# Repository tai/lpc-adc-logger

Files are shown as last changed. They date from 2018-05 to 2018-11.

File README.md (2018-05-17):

# 4-ch ADC Data Logger with LPC1114

This is a simple ADC data logger based on LPC1114FN28 microcontroller.
Primary motivation is to test and record battery runtime independently, without using large/external facility like a PC.

# Major Features
- Can measure voltage of 4 channels every minutes at 10-bit resolution
- Can stream data to serial port
- Can log data to FAT-formatted SD card (saves after every 60 samples)
- Can flush data to SD card with a button press
- Can erase data on SD card with a button press
- Can show activity/response to LEDs
- Supports battery-based, low power operation

# How to Build
```
$ git clone lpc-adc-logger
$ cd lpc-adc-logger
$ make
```

# How to Use
- Insert a SD card with a file LOG-00.TXT on its root folder.
- LOG-00.TXT must be prepared as a zero-filled file large enough to hold all log data.
-- Command `dd if=/dev/zero of=LOG-00.TXT bs=1024 count=1024` would do
- Pressing "Erase/Flush" button during powerup erases data in datafile.
- Pressing "Erase/Flush" button during operation flushes data to datafile.
- Connect UART to see a stream of currently sampled data.
- You can power off anytime - however, most recent page (256B) amount of data will be lost unless flushed by a button press.

# LED pattern meanings
- Fast blink - processing button press
- Slow blink - in operation

# Pinouts
- dp1  - SD card (MISO)
- dp2  - SD card (MOSI)
- dp3  - SWD (SWDCLK)
- dp4  - ADC ch#0
- dp5  - NC (reserved for I2C-SDA)
- dp6  - SD card (SCLK)
- dp7  - Analog VCC
- dp8  - Analog GND
- dp9  - ADC ch#1
- dp10 - ADC ch#2
- dp11 - ADC ch#3
- dp12 - SWD (SWDIO)
- dp13 - NC (reserved for PWM/WAKEUP)
- dp14 - Button #1 (Flush/Erase Button)
- dp15 - Serial RX
- dp16 - Serial TX
- dp17 - NC (reserved for button)
- dp18 - NC (reserved for PWM)
- dp19 - NC (XTALOUT)
- dp20 - NC (XTALIN)
- dp21 - VCC
- dp22 - GND
- dp23 - RESET
- dp24 - NC (reserved for CLKOUT)
- dp25 - SD card (SSEL)
- dp26 - LED #1
- dp27 - NC (reserved for I2C-SCL)
- dp28 - NC (reserved for LED #2)

# Schematic

# Notes
- Already functional, but currently under development. 
- Sampling rate is currently 1 sample/s, will make it 1 sample/min in final version.

# See Also
- PlatformIO
- BlackMagic
- mBed
- PFF

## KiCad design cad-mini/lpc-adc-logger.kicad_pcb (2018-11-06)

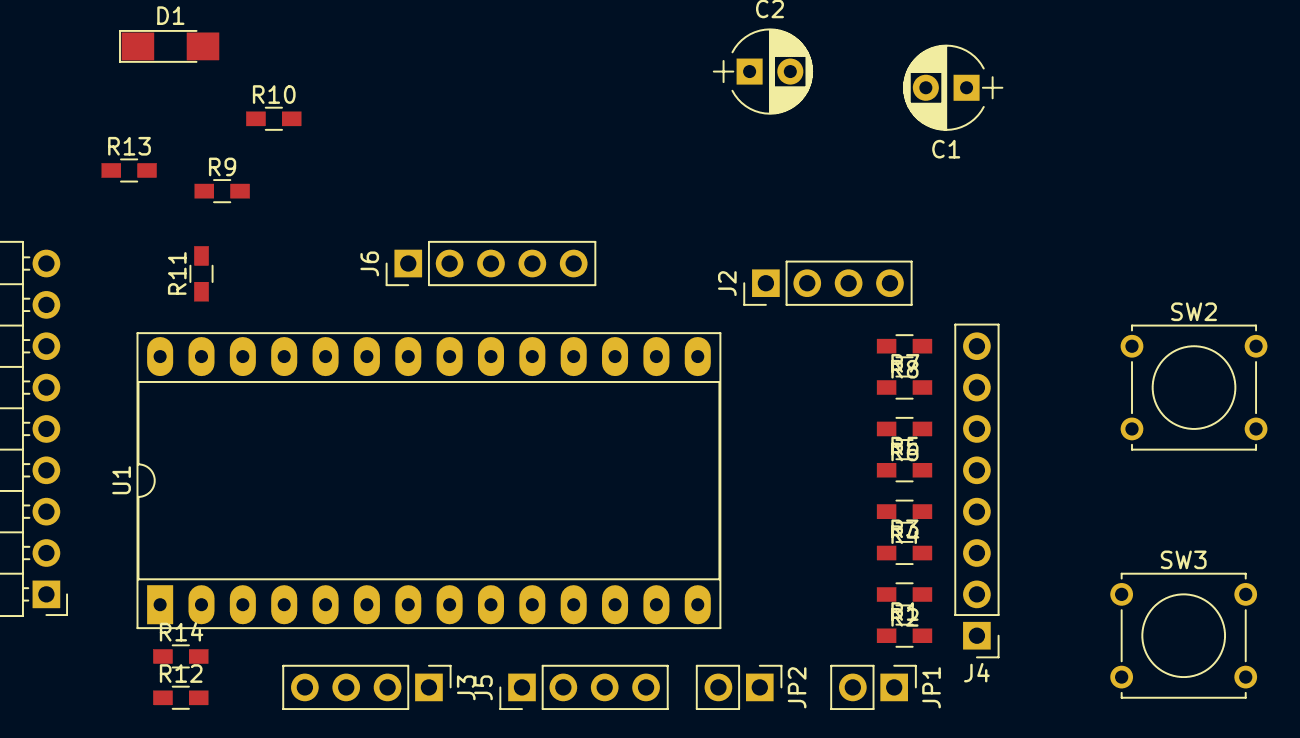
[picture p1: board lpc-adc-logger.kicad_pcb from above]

Board: 2 copper layers, 28 parts (0 on the bottom side), 29 nets, no tracks yet.

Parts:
C1, C2: 10uF; CP_Radial_D5.0mm_P2.50mm
D1: LED; LED_1206_HandSoldering
J1: SD/SPI; Pin_Header_Angled_1x09_Pitch2.54mm
J2: UART; Pin_Header_Straight_1x04_Pitch2.54mm
J3: I2C; Pin_Header_Straight_1x04_Pitch2.54mm
J4: ANALOG IN; Pin_Header_Straight_1x08_Pitch2.54mm
J5: SWD; Pin_Header_Straight_1x04_Pitch2.54mm
J6: GPIO; Pin_Header_Straight_1x05_Pitch2.54mm
JP1: RATE; Pin_Header_Straight_1x02_Pitch2.54mm
JP2: CARD; Pin_Header_Straight_1x02_Pitch2.54mm
R1, R2, R3, R4, R5, R6, R7, R8, R11, R12: 4.7K; R_0603_HandSoldering
R9: 330; R_0603_HandSoldering
R10: 10K; R_0603_HandSoldering
R13, R14: 47K; R_0603_HandSoldering
SW2: RESET; SW_Tactile_Straight_KSA0Axx1LFTR
SW3: FLUSH; SW_Tactile_Straight_KSA0Axx1LFTR
U1: LPC1114FN28; DIP-28_W15.24mm_Socket_LongPads

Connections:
/CLK: J1.6, U1.6
/CMD/MOSI: J1.3, R14.1, U1.2
/DAT0/MISO: J1.8, R13.1, U1.1
/DAT3/CS: J1.2, U1.25
GND: C1.2, C2.2, J1.4, J1.7, J2.1, J3.1, J4.2, J4.4, J4.6, J4.8, J5.1, J6.1, JP1.1, JP2.1, R2.1, R4.1, R6.1, R8.1, SW2.2, SW3.2, U1.8, U1.22
unnamed: D1.1, U1.28
unnamed: D1.2, R9.1
unnamed: J2.3, U1.16
unnamed: J2.4, U1.15
unnamed: J3.3, R11.1, U1.27
unnamed: J3.4, R12.1, U1.5
unnamed: J4.1, R1.2
unnamed: J4.3, R3.2
unnamed: J4.5, R5.2
unnamed: J4.7, R7.2
unnamed: J5.3, U1.3
unnamed: J5.4, U1.12
unnamed: J6.3, U1.24
unnamed: J6.4, U1.18
unnamed: J6.5, U1.17
unnamed: JP1.2, U1.13
unnamed: JP2.2, U1.14
unnamed: R1.1, R2.2, U1.4
unnamed: R3.1, R4.2, U1.9
unnamed: R5.1, R6.2, U1.10
unnamed: R7.1, R8.2, U1.11
unnamed: R10.1, SW2.1, U1.23
unnamed: SW3.1, U1.26
VCC: C1.1, C2.1, J1.5, J2.2, J3.2, J5.2, J6.2, R9.2, R10.2, R11.2, R12.2, R13.2, R14.2, U1.7, U1.21

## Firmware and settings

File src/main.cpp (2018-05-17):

//
// ADC Data Logger
//

#include "mbed.h"
#include "pt.h"
#include "pff/pff.h"
#include "semihost.h"
#include "PinDetect.h"

#if DEVICE_SEMIHOST
#define log semihost_printf
#else
#define log printf
#endif

AnalogIn ad0(dp4), ad1(dp9), ad2(dp10), ad3(dp11);
DigitalOut led1(dp26);

PinDetect saveButton(dp14);
DigitalIn saveButtonRaw(dp14);

Ticker readTicker;
Ticker blinkTicker;

#define NR_ELEM(a) (sizeof(a) / sizeof(a[0]))

#define MAGIC 0xDEADBEEF

// Record to hold sampled data
// Must fit into single FAT sector (512B)
struct logdata_t {
    uint32_t magic;   //   4B
    uint8_t length;   //   1B
    uint8_t skip[27]; //  27B
    struct {          // 480B
        uint16_t ad[4];
    } sample[60];
};

// Global context to pass around
struct ctx_t {
    FATFS fs;
    logdata_t log;

    bool is_key_pressed;
    bool is_ready_to_read;
    bool is_ready_to_save;
} ctx;

void
init_sd() {
    FRESULT rc;

    //
    // Elm-chan's PFF (Petit FAT FS) library is small, but has many
    // limitations like below:
    //
    // - It only supports access to existing file
    // - There is no filehandle - only one file can be opened at once
    //
    // Here, we do basic setup so further logging can be done just by
    // calling series of pf_write API.
    //
    
    rc = pf_mount(&ctx.fs);
    log("pf_mount: %d\r\n", rc);

    rc = pf_open("TEST.TXT");
    log("pf_open: %d\r\n", rc);

    // TODO: skip existing data to support appending
    if (false) {
        WORD nr;
        uint32_t magic = 0;
        rc = pf_read(&magic, sizeof(magic), &nr);
        log("pf_read: %d\r\n", rc);

        rc = pf_lseek(0);
        log("pf_lseek: %d\r\n", rc);
    }
}

void
init() {
    log("init: entered\r\n");

    // init context
    ctx.log.magic = MAGIC;

    // init SD card
    init_sd();

    // start blinking
    blinkTicker.attach_us([]() -> void { led1 = !led1; }, 1000000);

    // start sampling
    readTicker.attach_us([]() -> void { ctx.is_ready_to_read = true; }, 1000000);

    // start input-check
    saveButton.attach_asserted([]() -> void { ctx.is_key_pressed = true; });
}

//
// Task to check user input.
// Currently, there's not much to check as there is only one button
// that triggers a save action.
//
PT_THREAD(check_pin_task(pt *pt)) {
    PT_BEGIN(pt);

    for (;;) {
        PT_WAIT_UNTIL(pt, ctx.is_key_pressed);
        ctx.is_key_pressed = false;
        ctx.is_ready_to_save = true;

        log("key press detected.\r\n");
    }
    PT_END(pt);
}

//
// Task to read ADC data.
// Also streams data out to serial port and triggers a save when
// buffer is full.
//
PT_THREAD(data_read_task(pt *pt)) {
    PT_BEGIN(pt);

    static uint32_t tick;

    for (;;) {
        PT_WAIT_UNTIL(pt, ctx.is_ready_to_read);
        ctx.is_ready_to_read = false;

        auto& sample = ctx.log.sample[ctx.log.length++];
        sample.ad[0] = ad0.read_u16();
        sample.ad[1] = ad1.read_u16();
        sample.ad[2] = ad2.read_u16();
        sample.ad[3] = ad3.read_u16();

        log("%u,%04X,%04X,%04X,%04X\r\n",
            tick++, sample.ad[0], sample.ad[1], sample.ad[2], sample.ad[3]);

        if (ctx.log.length >= NR_ELEM(ctx.log.sample)) {
            ctx.is_ready_to_save = true;
        }
    }
    PT_END(pt);
}

//
// Task to save current data when triggered.
//
PT_THREAD(data_save_task(pt *pt)) {
    PT_BEGIN(pt);

    for (;;) {
        PT_WAIT_UNTIL(pt, ctx.is_ready_to_save);
        ctx.is_ready_to_save = false;

        log("saving data...\r\n");

        FRESULT rc;
        WORD nr;

        rc = pf_write(&ctx.log, sizeof(ctx.log), &nr);
        log("pf_write: %d, nr=%d\r\n", rc, nr);

        rc = pf_write(0, 0, &nr);
        log("pf_write(0): %d, nr=%d\r\n", rc, nr);

        ctx.log.length = 0;
    }
    PT_END(pt);
}

int
main() {
    pt pt1, pt2, pt3, pt4;

    init();

    for (;;) {
        check_pin_task(&pt1);
        data_read_task(&pt3);
        data_save_task(&pt2);
        sleep();
    }
    return 0;
}

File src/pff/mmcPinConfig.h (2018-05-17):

#ifndef MMCPINCONFIG_H
#define MMCPINCONFIG_H

// pin configurations
#define MMC_MISO dp1
#define MMC_MOSI dp2
#define MMC_SCLK dp6
#define MMC_CS dp25

#endif

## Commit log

2018-05-17 Initial prototype.
2018-05-18 Added basic components
    [lpc-adc-logger.kicad_pcb, lpc-adc-logger.sch]
2018-05-21 Updated schematic.
    [lpc-adc-logger.sch]
2018-05-23 Added KiCAD files.
    [lpc-adc-logger.dsn, lpc-adc-logger.kicad_pcb, lpc-adc-logger.sch]
2018-05-23 - Fixed SD card MMC-CS pin - Added GPIO header - Added I2C header
    [lpc-adc-logger.dsn, lpc-adc-logger.kicad_pcb, lpc-adc-logger.sch]
2018-05-24 [WIP] Added SPI header.
    [lpc-adc-logger.kicad_pcb, lpc-adc-logger.sch]
2018-11-06 Minor update
    [lpc-adc-logger.sch]
2018-11-06 Added kicad design for mini board
    [lpc-adc-logger.dsn, lpc-adc-logger.kicad_pcb, lpc-adc-logger.sch]
